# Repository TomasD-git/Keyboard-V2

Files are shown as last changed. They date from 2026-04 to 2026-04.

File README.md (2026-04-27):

# Keyboard-V2
**small, compact keyboard for everyday use.**


## Layout

```
["Esc","1","2","3","4","5","6","7","8","9","0","-","=",{w:2},"Backspace"],
[{w:1.5},"Tab","Q","W","E","R","T","Y","U","I","O","P","[","]",{w:1.5},"\\"],
[{w:1.75},"Caps","A","S","D","F","G","H","J","K","L",";","'",{w:2.25},"Enter"],
[{w:2.25},"Shift","Z","X","C","V","B","N","M",",",".","/",{w:2.75},"Shift"],
[{w:1.25},"Ctrl",{w:1.25},"Win",{w:1.25},"Alt",{w:6.25},"Space",{w:1.25},"Alt",{w:1.25},"Fn",{w:1.25},"Ctrl",{w:1.25},"Esc"]
```

```
        C1  , C2  ,C3 , C4  ,  C5 , C6  ,  C7  , C8  ,  C9 ,  C10 , C11,C12, C13 ,    C14
Row 1 [    ;,    1,  2,    3,    4,    5,     6,    7,    8,     9,   0,  -,    =, backspace]
Row 2 [  tap,    q,  w,    e,    r,    t,     y,    u,    i,     o,   p,  [,    ],    /     ]
Row 3 [ Caps,    a,  s,    d,    f,    g,     h,    j,    k,     l,   ;,  ', Null,   Enter  ]
Row 4 [Shift, Null,  z,    x,    c,    v,     b,    n,    m, comma,   .,  /, Null,  Shift   ]
Row 5 [Ctrl , Win, Alt, Null, Null, Null, Space, Null, Null,  Null, Alt, Fn, Ctrl,  Esc     ]
```

## Features
- Compact 60% layout
- Powered by RPi pico
- Dedicated Fn layer
- Smooth switches
- Stabilizers
- Custom CAD
- Custom PCB

## How It Works
The Keyboard-V2 uses a key matrix to scan all rows and columms. The Fn key enables a secondary layer for additional functionality. The case is 3D printed, with custom PCB and.

<details>
  <summary>Pictures</summary>










</details>

<details>
<summary>BOM</summary>

| Name | Purpose | Quantity | Total Cost (USD) | Link | Distributor |
|---|---|---|---|---|---|
| Stabilizers | Stabilizers are used so keys arent wobly and are in place | 1 | 8.00 | https://www.aliexpress.com/item/1005006528731543.html | Aliexpress |
| PCB | On the PCB are all components | 1 | 44.11 | https://jlcpcb.com | JlcPCB |
| Key switch | the actual switch u press to get a signal | 1 | 21.00 | https://www.aliexpress.com/item/1005007459638140.html | Aliexpress |
| Diodes | prevents ghosting | 1 | 3.00 | https://www.aliexpress.com/item/1005007160563285.html | Aliexpress |
| RPi Pico | Brain of the whole keyboard | 1 | 4.30 | https://www.aliexpress.com/item/1005008714908011.html | Aliexpress |
| M2 screws | Small set of M2 screws to hold the keyboard in place | 1 | 7.40 | https://www.aliexpress.com/item/1005006827233117.html | Aliexpress |
| M2xL3xOD3.2, Heatset inserts | Will hold the keyboard together with screws | 1 | 5.00 | https://www.aliexpress.com/item/1005006838108683.html | Aliexpress |
| Keycaps | are on switches | 1 | 15.00 | https://www.aliexpress.com/item/1005007360831985.html | Aliexpress |

</details>

<details>
  <summary>License</summary>

## MIT License

**Copyright (c) 2026 TomasD-git**

Permission is hereby granted, free of charge, to any person obtaining a copy
of this software and associated documentation files (the "Software"), to deal
in the Software without restriction, including without limitation the rights
to use, copy, modify, merge, publish, distribute, sublicense, and/or sell
copies of the Software, and to permit persons to whom the Software is
furnished to do so, subject to the following conditions:

The above copyright notice and this permission notice shall be included in all
copies or substantial portions of the Software.

THE SOFTWARE IS PROVIDED "AS IS", WITHOUT WARRANTY OF ANY KIND, EXPRESS OR
IMPLIED, INCLUDING BUT NOT LIMITED TO THE WARRANTIES OF MERCHANTABILITY,
FITNESS FOR A PARTICULAR PURPOSE AND NONINFRINGEMENT. IN NO EVENT SHALL THE
AUTHORS OR COPYRIGHT HOLDERS BE LIABLE FOR ANY CLAIM, DAMAGES OR OTHER
LIABILITY, WHETHER IN AN ACTION OF CONTRACT, TORT OR OTHERWISE, ARISING FROM,
OUT OF OR IN CONNECTION WITH THE SOFTWARE OR THE USE OR OTHER DEALINGS IN THE
SOFTWARE.

</details>

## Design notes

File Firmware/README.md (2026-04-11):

# Here is you can find firmware files  
## Down here is setup:  
## Step 1 — Flash CircuitPython onto the Pico

-   Download the [CircuitPython](https://circuitpython.org/board/raspberry_pi_pico/) UF2 for Raspberry Pi Pico

-   Hold the **BOOTSEL** button on your Pico and plug it into USB.  
-   A drive called **RPI-RP2** will appear on your computer.  

-    Drag and drop the .uf2 file onto that drive.  
-    The Pico will reboot and a new drive called **CIRCUITPY** will appear.  

## Step 2 — Install KMK

- 1 Go to [Kmk github](https://github.com/KMKfw/kmk_firmware) and click **Code → Download ZIP**
- 2 Unzip it
- 3 Copy the **`kmk/`** folder from inside the zip into the root of the **CIRCUITPY** drive

## Step 3 — Copy your keyboard config

Copy the **code.py** file into the root of the **CIRCUITPY** drive.

## Thats it  
**pico will automaticly run kmk on boot**

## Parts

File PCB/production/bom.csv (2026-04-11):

Designator | Footprint | Quantity | Value | LCSC Part #
D1, D10, D11, D12, D13, D14, D15, D16, D17, D18, D19, D2, D20, D21, D22, D23, D24, D25, D26, D27, D28, D29, D3, D30, D31, D32, D33, D34, D35, D36, D37, D38, D39, D4, D40, D41, D42, D43, D44, D45, D46, D47, D48, D49, D5, D50, D51, D52, D53, D54, D55, D56, D57, D58, D59, D6, D60, D61, D7, D8, D9 | D_SOD-123 | 61 | 1N4148WT
SW1, SW10, SW11, SW12, SW13, SW16, SW17, SW18, SW19, SW2, SW20, SW21, SW22, SW23, SW24, SW25, SW26, SW27, SW3, SW30, SW31, SW32, SW33, SW34, SW35, SW36, SW37, SW38, SW39, SW4, SW40, SW43, SW44, SW45, SW46, SW47, SW48, SW49, SW5, SW50, SW51, SW52, SW6, SW7, SW8, SW9 | SW_Cherry_MX_PCB_1.00u | 46 | SW_Push
SW14 | SW_Cherry_MX_2.00u_PCB | 1 | SW_Push
SW15, SW28 | SW_Cherry_MX_PCB_1.50u | 2 | SW_Push
SW29 | SW_Cherry_MX_PCB_1.75u | 1 | SW_Push
SW41, SW42 | SW_Cherry_MX_2.25u_PCB | 2 | SW_Push
SW53 | SW_Cherry_MX_2.75u_PCB | 1 | SW_Push
SW54, SW55, SW56, SW58, SW59, SW60, SW61 | SW_Cherry_MX_PCB_1.25u | 7 | SW_Push
SW57 | SW_Cherry_MX_6.25u_PCB | 1 | SW_Push
U1 | RPi_Pico_SMD_TH | 1 | Pico

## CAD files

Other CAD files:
CAD/Keyboard V2.f3z

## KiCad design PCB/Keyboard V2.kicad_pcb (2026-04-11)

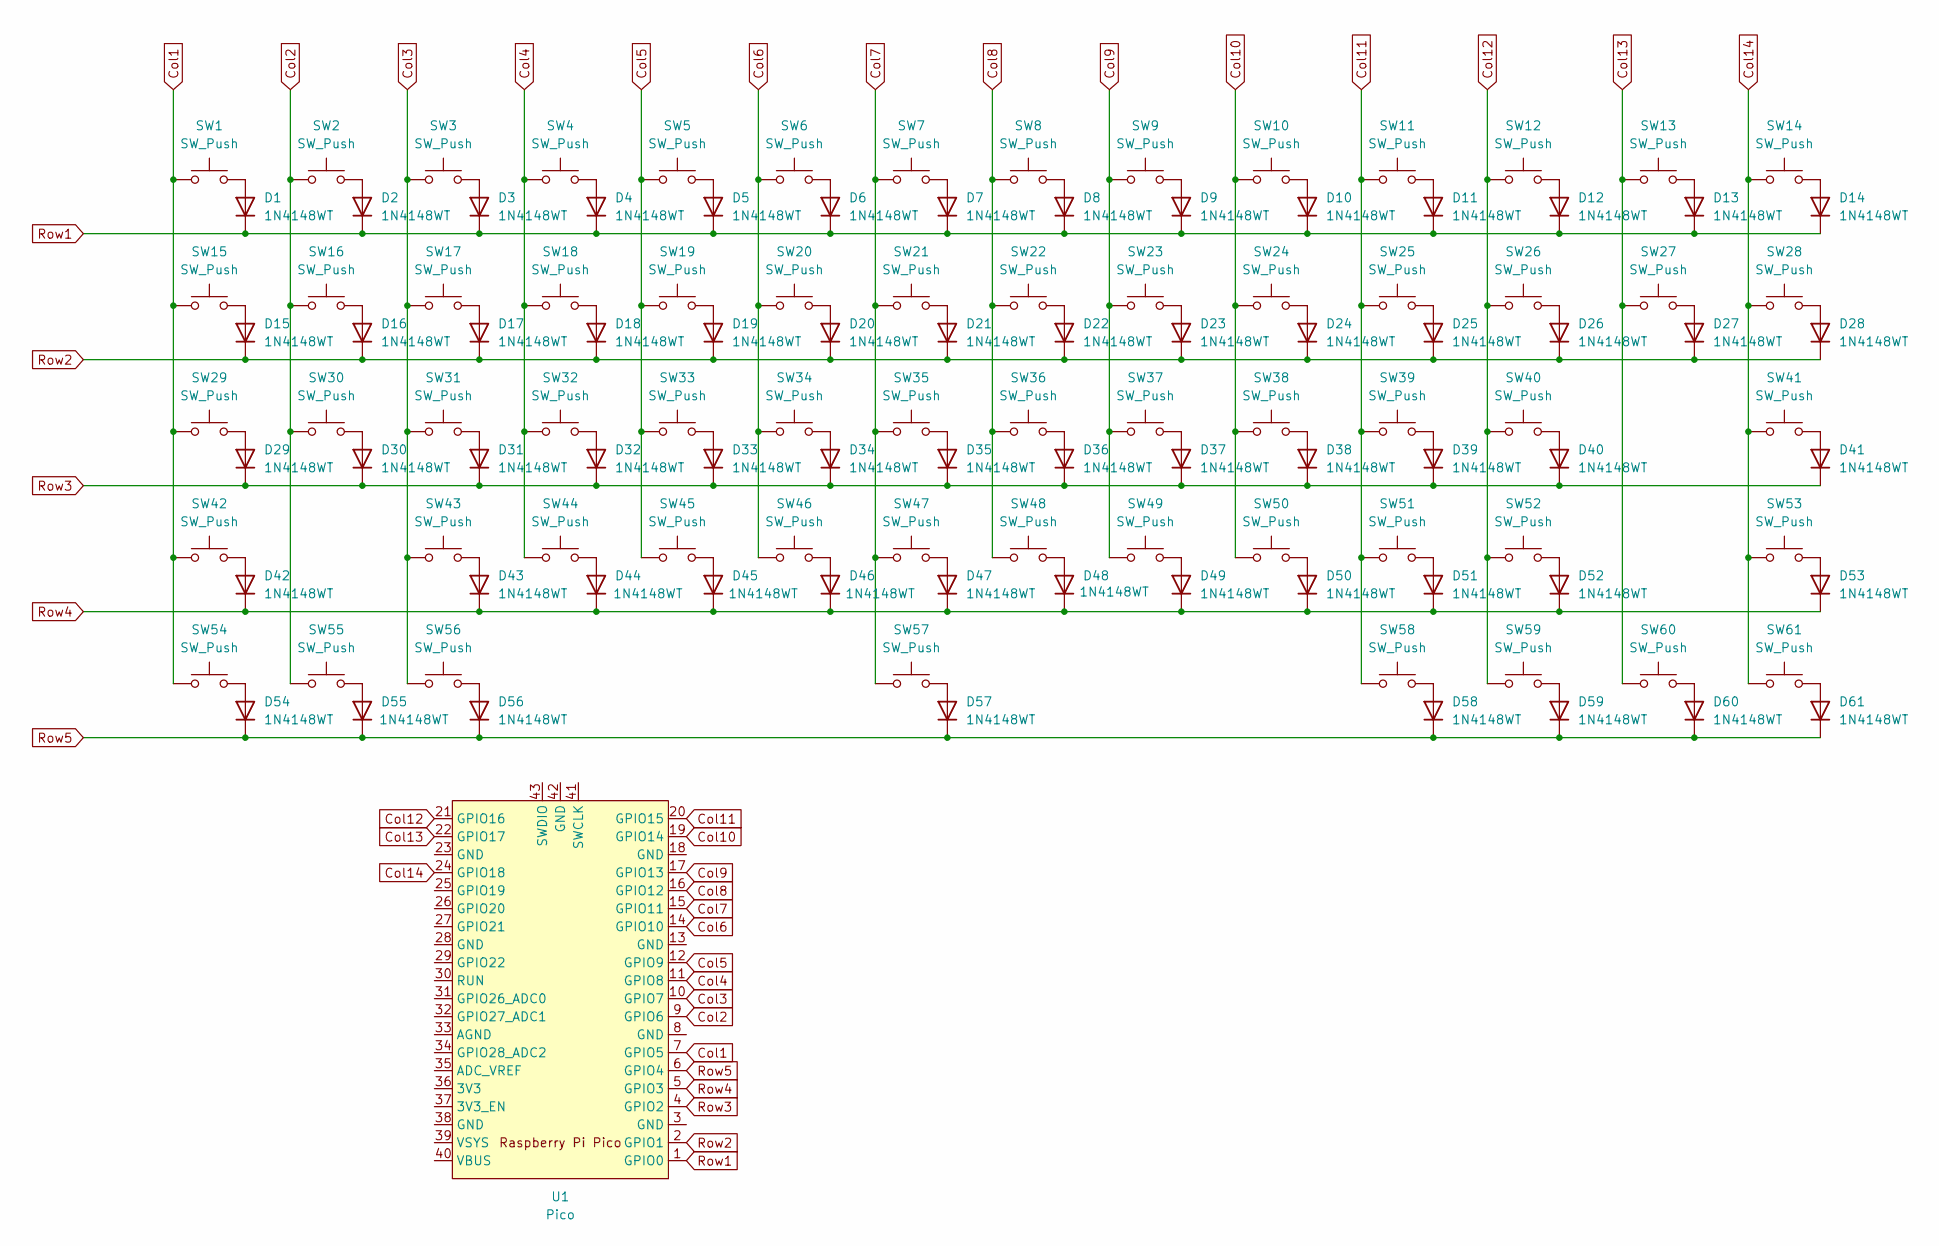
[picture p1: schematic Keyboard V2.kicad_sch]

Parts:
D1, D2, D3, D4, D5, D6, D7, D8, D9, D10, D11, D12, D13, D14, D15, D16, D17, D18, D19, D20, D21, D22, D23, D24, D25, D26, D27, D28, D29, D30, D31, D32, D33, D34, D35, D36, D37, D38, D39, D40, D41, D42, D43, D44, D45, D46, D47, D48, D49, D50, D51, D52, D53, D54, D55, D56, D57, D58, D59, D60, D61: 1N4148WT; D_SOD-123
SW1, SW2, SW3, SW4, SW5, SW6, SW7, SW8, SW9, SW10, SW11, SW12, SW13, SW16, SW17, SW18, SW19, SW20, SW21, SW22, SW23, SW24, SW25, SW26, SW27, SW30, SW31, SW32, SW33, SW34, SW35, SW36, SW37, SW38, SW39, SW40, SW43, SW44, SW45, SW46, SW47, SW48, SW49, SW50, SW51, SW52: SW_Push; SW_Cherry_MX_PCB_1.00u
SW14: SW_Push; SW_Cherry_MX_2.00u_PCB
SW15, SW28: SW_Push; SW_Cherry_MX_PCB_1.50u
SW29: SW_Push; SW_Cherry_MX_PCB_1.75u
SW41, SW42: SW_Push; SW_Cherry_MX_2.25u_PCB
SW53: SW_Push; SW_Cherry_MX_2.75u_PCB
SW54, SW55, SW56, SW58, SW59, SW60, SW61: SW_Push; SW_Cherry_MX_PCB_1.25u
SW57: SW_Push; SW_Cherry_MX_6.25u_PCB
U1: Pico; RPi_Pico_SMD_TH

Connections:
Col1: SW1.1, SW15.1, SW29.1, SW42.1, SW54.1, U1.7 (GPIO5)
Col2: SW2.1, SW16.1, SW30.1, SW55.1, U1.9 (GPIO6)
Col3: SW3.1, SW17.1, SW31.1, SW43.1, SW56.1, U1.10 (GPIO7)
Col4: SW4.1, SW18.1, SW32.1, SW44.1, U1.11 (GPIO8)
Col5: SW5.1, SW19.1, SW33.1, SW45.1, U1.12 (GPIO9)
Col6: SW6.1, SW20.1, SW34.1, SW46.1, U1.14 (GPIO10)
Col7: SW7.1, SW21.1, SW35.1, SW47.1, SW57.1, U1.15 (GPIO11)
Col8: SW8.1, SW22.1, SW36.1, SW48.1, U1.16 (GPIO12)
Col9: SW9.1, SW23.1, SW37.1, SW49.1, U1.17 (GPIO13)
Col10: SW10.1, SW24.1, SW38.1, SW50.1, U1.19 (GPIO14)
Col11: SW11.1, SW25.1, SW39.1, SW51.1, SW58.1, U1.20 (GPIO15)
Col12: SW12.1, SW26.1, SW40.1, SW52.1, SW59.1, U1.21 (GPIO16)
Col13: SW13.1, SW27.1, SW60.1, U1.22 (GPIO17)
Col14: SW14.1, SW28.1, SW41.1, SW53.1, SW61.1, U1.24 (GPIO18)
unnamed: D1.2 (A), SW1.2
unnamed: D2.2 (A), SW2.2
unnamed: D3.2 (A), SW3.2
unnamed: D4.2 (A), SW4.2
unnamed: D5.2 (A), SW5.2
unnamed: D6.2 (A), SW6.2
unnamed: D7.2 (A), SW7.2
unnamed: D8.2 (A), SW8.2
unnamed: D9.2 (A), SW9.2
unnamed: D10.2 (A), SW10.2
unnamed: D11.2 (A), SW11.2
unnamed: D12.2 (A), SW12.2
unnamed: D13.2 (A), SW13.2
unnamed: D14.2 (A), SW14.2
unnamed: D15.2 (A), SW15.2
unnamed: D16.2 (A), SW16.2
unnamed: D17.2 (A), SW17.2
unnamed: D18.2 (A), SW18.2
unnamed: D19.2 (A), SW19.2
unnamed: D20.2 (A), SW20.2
unnamed: D21.2 (A), SW21.2
unnamed: D22.2 (A), SW22.2
unnamed: D23.2 (A), SW23.2
unnamed: D24.2 (A), SW24.2
unnamed: D25.2 (A), SW25.2
unnamed: D26.2 (A), SW26.2
unnamed: D27.2 (A), SW27.2
unnamed: D28.2 (A), SW28.2
unnamed: D29.2 (A), SW29.2
unnamed: D30.2 (A), SW30.2
unnamed: D31.2 (A), SW31.2
unnamed: D32.2 (A), SW32.2
unnamed: D33.2 (A), SW33.2
unnamed: D34.2 (A), SW34.2
unnamed: D35.2 (A), SW35.2
unnamed: D36.2 (A), SW36.2
unnamed: D37.2 (A), SW37.2
unnamed: D38.2 (A), SW38.2
unnamed: D39.2 (A), SW39.2
unnamed: D40.2 (A), SW40.2
unnamed: D41.2 (A), SW41.2
unnamed: D42.2 (A), SW42.2
unnamed: D43.2 (A), SW43.2
unnamed: D44.2 (A), SW44.2
unnamed: D45.2 (A), SW45.2
unnamed: D46.2 (A), SW46.2
unnamed: D47.2 (A), SW47.2
unnamed: D48.2 (A), SW48.2
unnamed: D49.2 (A), SW49.2
unnamed: D50.2 (A), SW50.2
unnamed: D51.2 (A), SW51.2
unnamed: D52.2 (A), SW52.2
unnamed: D53.2 (A), SW53.2
unnamed: D54.2 (A), SW54.2
unnamed: D55.2 (A), SW55.2
unnamed: D56.2 (A), SW56.2
unnamed: D57.2 (A), SW57.2
unnamed: D58.2 (A), SW58.2
unnamed: D59.2 (A), SW59.2
unnamed: D60.2 (A), SW60.2
unnamed: D61.2 (A), SW61.2
Row1: D1.1 (K), D2.1 (K), D3.1 (K), D4.1 (K), D5.1 (K), D6.1 (K), D7.1 (K), D8.1 (K), D9.1 (K), D10.1 (K), D11.1 (K), D12.1 (K), D13.1 (K), D14.1 (K), U1.1 (GPIO0)
Row2: D15.1 (K), D16.1 (K), D17.1 (K), D18.1 (K), D19.1 (K), D20.1 (K), D21.1 (K), D22.1 (K), D23.1 (K), D24.1 (K), D25.1 (K), D26.1 (K), D27.1 (K), D28.1 (K), U1.2 (GPIO1)
Row3: D29.1 (K), D30.1 (K), D31.1 (K), D32.1 (K), D33.1 (K), D34.1 (K), D35.1 (K), D36.1 (K), D37.1 (K), D38.1 (K), D39.1 (K), D40.1 (K), D41.1 (K), U1.4 (GPIO2)
Row4: D42.1 (K), D43.1 (K), D44.1 (K), D45.1 (K), D46.1 (K), D47.1 (K), D48.1 (K), D49.1 (K), D50.1 (K), D51.1 (K), D52.1 (K), D53.1 (K), U1.5 (GPIO3)
Row5: D54.1 (K), D55.1 (K), D56.1 (K), D57.1 (K), D58.1 (K), D59.1 (K), D60.1 (K), D61.1 (K), U1.6 (GPIO4)

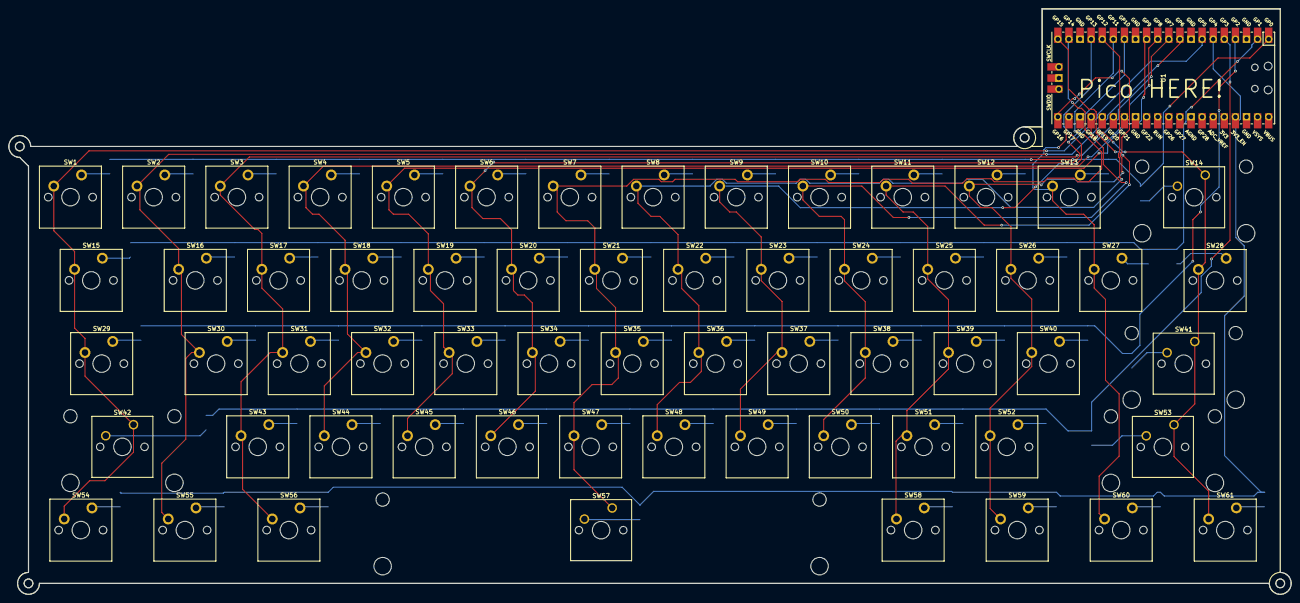
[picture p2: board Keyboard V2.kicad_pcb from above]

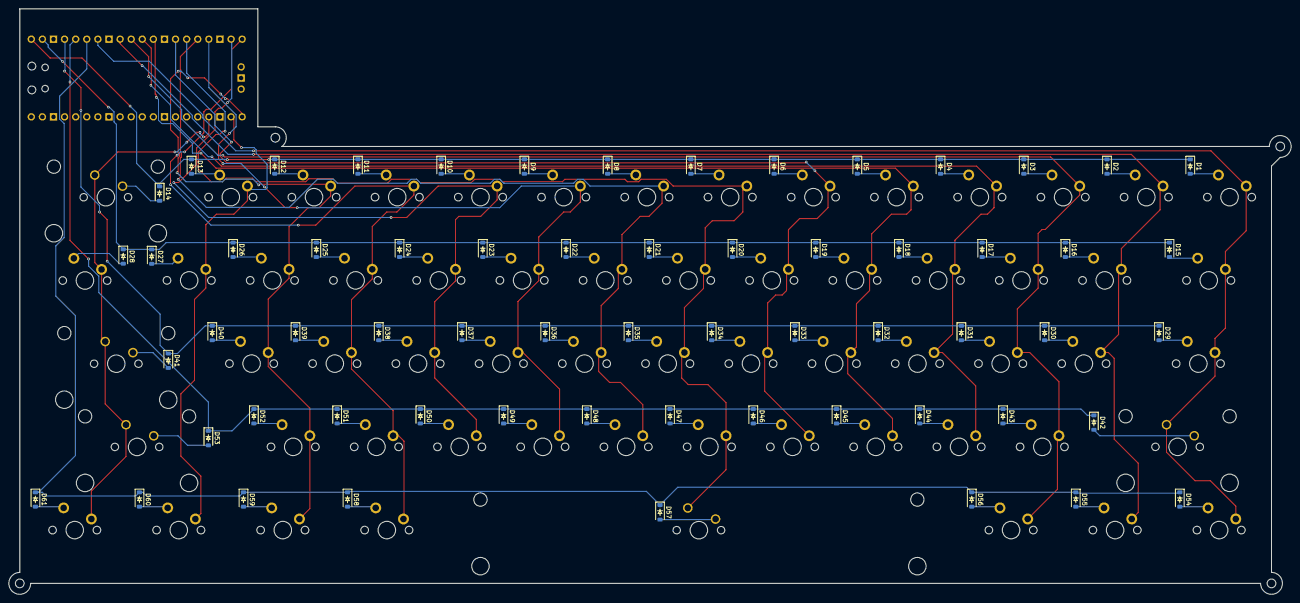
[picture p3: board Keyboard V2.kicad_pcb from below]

Board: 2 copper layers, 293.5 x 134.0 mm, 123 parts (61 on the bottom side), 80 nets.

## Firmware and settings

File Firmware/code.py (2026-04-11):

import board
from kmk.kmk_keyboard import KMKKeyboard
from kmk.keys import KC
from kmk.scanners import DiodeOrientation
from kmk.modules.layers import Layers

keyboard = KMKKeyboard()

keyboard.row_pins = (
    board.GP0,
    board.GP1,
    board.GP2,
    board.GP3,
    board.GP4,
)

keyboard.col_pins = (
    board.GP5,
    board.GP6,
    board.GP7,
    board.GP8,
    board.GP9,
    board.GP10,
    board.GP11,
    board.GP12,
    board.GP13,
    board.GP14,
    board.GP15,
    board.GP16,
    board.GP17,
    board.GP18,
)

keyboard.diode_orientation = DiodeOrientation.COL2ROW

layers = Layers()
keyboard.modules.append(layers)

FN = KC.MO(1)   

keyboard.keymap = [
    [
        KC.ESC,  KC.N1,   KC.N2,   KC.N3,   KC.N4,   KC.N5,   KC.N6,   KC.N7,   KC.N8,   KC.N9,   KC.N0,   KC.MINS, KC.EQL,  KC.BSPC,
        KC.TAB,  KC.Q,    KC.W,    KC.E,    KC.R,    KC.T,    KC.Y,    KC.U,    KC.I,    KC.O,    KC.P,    KC.LBRC, KC.RBRC, KC.BSLS,
        KC.CAPS, KC.A,    KC.S,    KC.D,    KC.F,    KC.G,    KC.H,    KC.J,    KC.K,    KC.L,    KC.SCLN, KC.QUOT, KC.NO,   KC.ENT,
        KC.LSFT, KC.NO,   KC.Z,    KC.X,    KC.C,    KC.V,    KC.B,    KC.N,    KC.M,    KC.COMM, KC.DOT,  KC.SLSH, KC.NO,   KC.RSFT,
        KC.LCTL, KC.LGUI, KC.LALT, KC.NO,   KC.NO,   KC.NO,   KC.SPC,  KC.NO,   KC.NO,   KC.NO,   KC.RALT, FN,      KC.RCTL, KC.ESC,
    ],
    [
        KC.TRNS, KC.F1,   KC.F2,   KC.F3,   KC.F4,   KC.F5,   KC.F6,   KC.F7,   KC.F8,   KC.F9,   KC.F10,  KC.F11,  KC.F12,  KC.DEL,
        KC.TRNS, KC.TRNS, KC.UP,   KC.TRNS, KC.TRNS, KC.TRNS, KC.TRNS, KC.TRNS, KC.TRNS, KC.TRNS, KC.PSCR, KC.SCRL, KC.PAUS, KC.TRNS,
        KC.TRNS, KC.LEFT, KC.DOWN, KC.RGHT, KC.TRNS, KC.TRNS, KC.TRNS, KC.TRNS, KC.TRNS, KC.TRNS, KC.TRNS, KC.TRNS, KC.NO,   KC.TRNS,
        KC.TRNS, KC.NO,   KC.TRNS, KC.TRNS, KC.TRNS, KC.VOLD, KC.VOLU, KC.MUTE, KC.TRNS, KC.TRNS, KC.TRNS, KC.TRNS, KC.NO,   KC.TRNS,
        KC.TRNS, KC.TRNS, KC.TRNS, KC.NO,   KC.NO,   KC.NO,   KC.TRNS, KC.NO,   KC.NO,   KC.NO,   KC.TRNS, KC.TRNS, KC.TRNS, KC.RELOAD,
    ],
]
if __name__ == '__main__':
    keyboard.go()

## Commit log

2026-04-10 Update links in README for keycaps and RPI pico
2026-04-10 Add link for M2xL3xOD3.2 heatset inserts
2026-04-11 Update README with firmware setup instructions
    Added detailed setup instructions for flashing CircuitPython and installing KMK on Raspberry Pi Pico.
2026-04-11 Add README.md for KiCad files
2026-04-11 added PCB files
    [Keyboard V2.kicad_pcb, Keyboard V2.kicad_sch, bom.csv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]
2026-04-11 Add README.md for CAD files
2026-04-11 added CAD files
    [Keyboard V2.f3z]
2026-04-11 added BOM
    [BOM.csv]
2026-04-24 Add BOM section to README
    Added a BOM section detailing components, their purposes, quantities, costs, and links.
2026-04-27 added bottom CAD file
2026-04-27 added pcb picture
